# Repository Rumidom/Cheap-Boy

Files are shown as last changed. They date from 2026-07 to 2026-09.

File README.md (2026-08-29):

# Cheap-Boy
<p align="center">
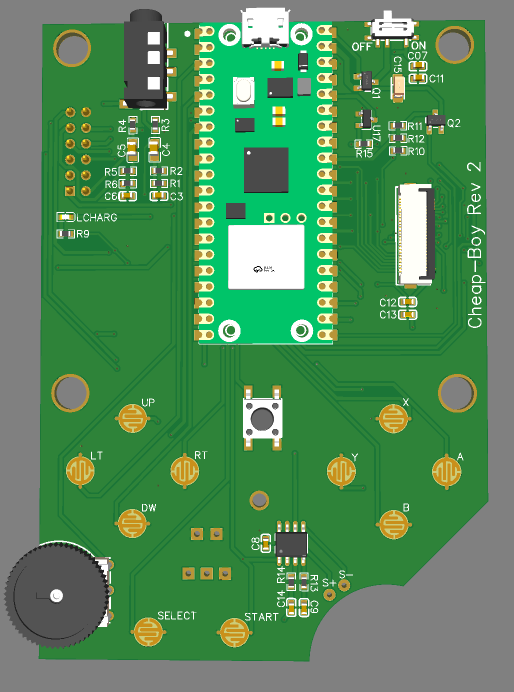
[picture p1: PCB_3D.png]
  
</p>

Cheap-Boy is a motherboard replacement mod for the [SUP 400 in 1](https://bootleggames.fandom.com/wiki/Sup_Game_Box) portable [famiclone](https://en.wikipedia.org/wiki/Famiclone) , the 'SUP 400 in 1' handheld is an interesting piece of Chinese engineering on its own. It has a full NES on a chip, a rechargeable battery, Game-Boy DMG inspired shell, AV output, and can be found on Aliexpress for about U$10 or lower.

I thought it would be interesting to try to replace the main board on this device with one featuring a micro-controller such as the Raspberry Pi Pico, to emulate Game-Boy games. There are already a few emulator projects online leveraging the power of modern micro-controllers for gameboy and retro emulation: [RP2040-GB ](https://github.com/deltabeard/RP2040-GB), [Pico GB](https://github.com/YouMakeTech/Pico-GB), [Walnut-CGB](https://github.com/Mr-PauI/Walnut-CGB
), [retro-go](https://github.com/ducalex/retro-go), [Microbyte](https://hackaday.io/project/176182-microbyte)

Using the components of the sup 400 in 1 should yield an ultra cheap and reasonably powerful handheld. The sup 400 in 1 has already been [reversed enginered](https://hackaday.io/project/175322-dissecting-a-hand-held-noac-console-sup-400-in-1) to support a custom ROM. But as far as I'm aware this is the first attempt at running Game-Boy games on it. 

If you are allergic to cheap white label hardware and would like a more polished and authentic gaming experience, I recommend the [Super DMG](https://github.com/kamicane/Super-DMG-01) which restores new life to actual Nintendo silicon, or the [Gamebub](https://github.com/elipsitz/gamebub) which replicates the Game-Boy hardware on a FPGA aiming at high accuracy, in keeping with the theme, on this project I'll try to reuse as many components from the the SUP 400 in 1 as possible, add a few inexpensive new ones, and try to keep the total cost low. While having a complete feature set.

# Micro-controlers alternatives 

This board is designed for the Raspberry Pi Pico or any of the generic RP2040 variants, but different flavors of micro-controller could be used. There are a few dev board alternatives that share the same form factor and should be compatible. such as the [Wallnut Pico W](https://wiki.walnutpi.com/en/docs/walnutpi_picow/intro/wpi_picow), [ESP32-S3 Pico](https://www.waveshare.com/wiki/ESP32-S3-Pico) or any of the [Raspberry Pico series](https://www.raspberrypi.com/documentation/microcontrollers/pico-series.html#pico2)

## TODO:
- [x] Reverse Engineer 16-bit screen protocol
- [X] Create first revision of the PCB   
- [ ] Write a Screen library for the ILI934X (might need multiple later on, for other types of screen)

## License:
This project is MIT licensed.

## Support


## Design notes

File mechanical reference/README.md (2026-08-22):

# PCB dimensions 

<p align="center">
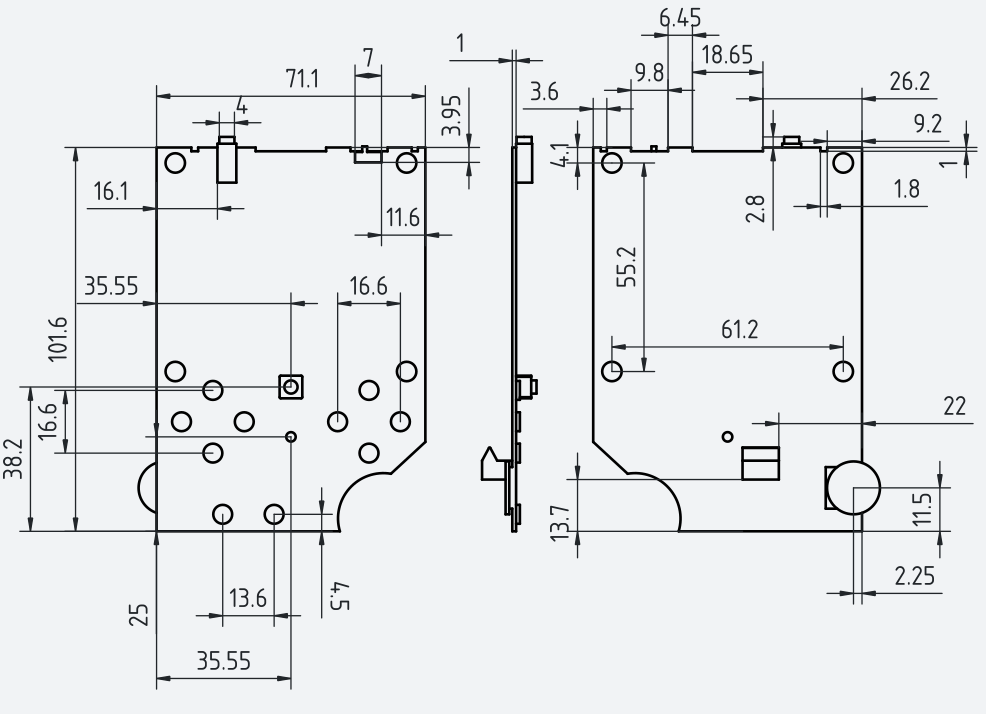
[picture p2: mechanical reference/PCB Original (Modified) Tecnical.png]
  
</p>

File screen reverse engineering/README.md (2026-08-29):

## The Screen
The screen is a 2.4 Inch 240*320 Dots TFT LCD 
<p align="center">
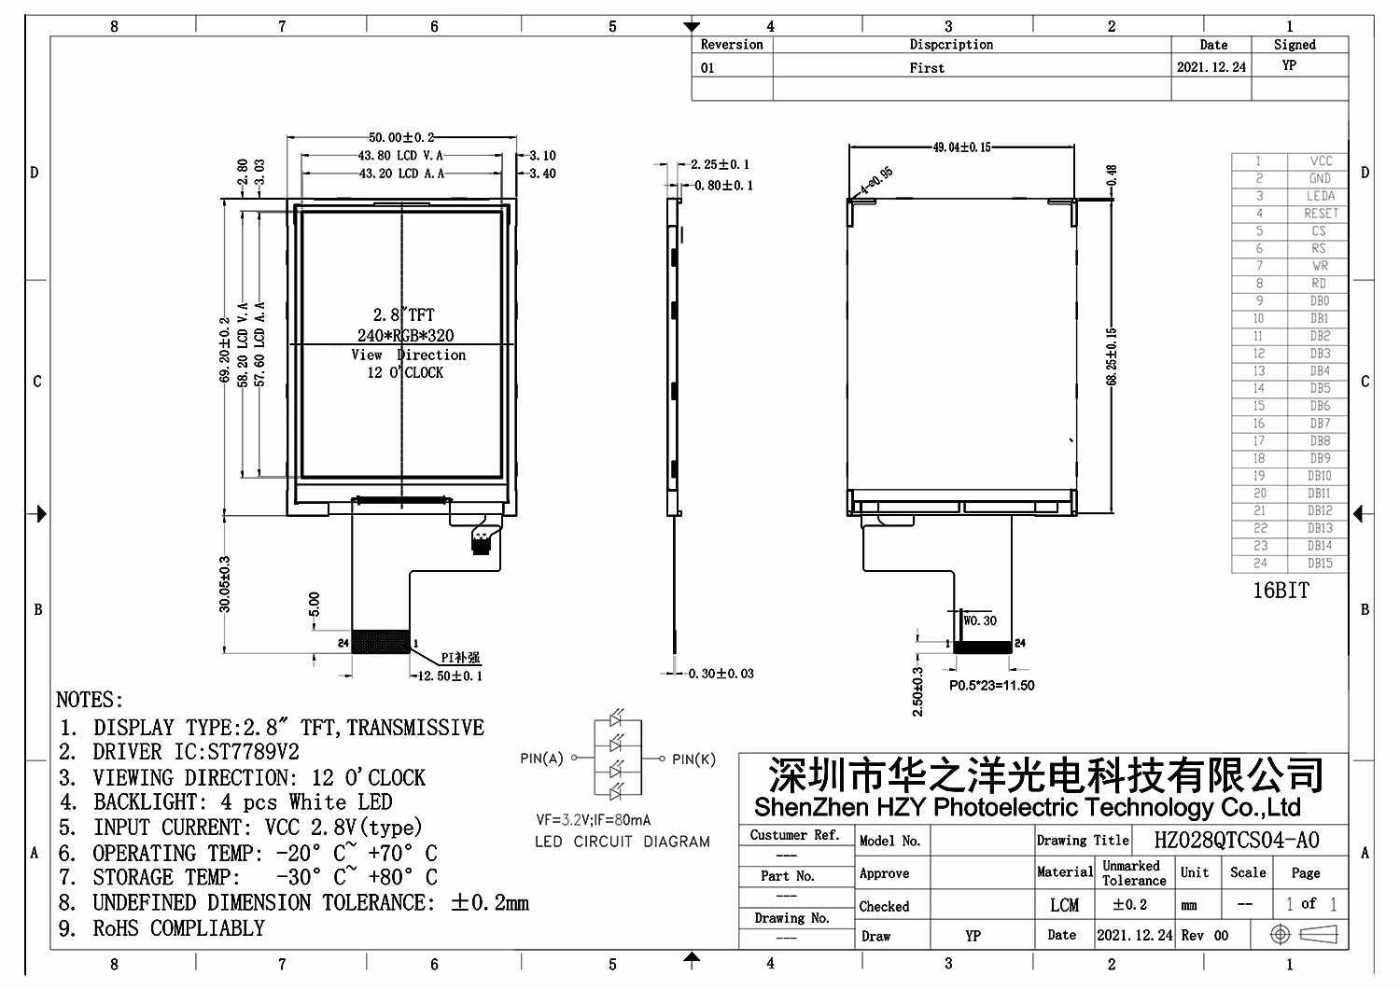
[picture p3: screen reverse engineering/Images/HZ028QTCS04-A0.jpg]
  
</p>

## Reference links
[Alibaba HZ028QTCS04-A0](https://www.alibaba.com/product-detail/China-Manufacturer-s-ST7789V-240-X_1600553862839.html)  
[TWJ28167A0](https://www.alibaba.com/product-detail/2-8-Tft-Lcd-Display-Module_1600589508979.html)  
[TFT024B045](https://www.alibaba.com/product-detail/2-4-240-X-320-TFT_1600669828556.html)  

## Datasheets
[CT024TN01 - Spec Sheet](https://github.com/Rumidom/Cheap-Boy/blob/main/datasheets/CT024TN01_INNOLUX_2.4__A-si_TFT-LCD_Panel_(EN).pdf)  
[ILI9340](https://github.com/Rumidom/Cheap-Boy/blob/main/datasheets/ILI9340.pdf)  
[ILI9341](https://github.com/Rumidom/Cheap-Boy/blob/main/datasheets/ILI9341.pdf)  
[ST7789V](https://github.com/Rumidom/Cheap-Boy/blob/main/datasheets/ST7789V.PDF)  

## Screen Reverse Engineering

### 29/07/2026:
as per the reverse enginering done by [YH-workshop](http://hackaday.io/project/175322-dissecting-a-hand-held-noac-console-sup-400-in-1/log/184885-tft-connections) the screen seems to be based on the ST7789V chipset, and its 2.4 Inch 240*320 Dots, there are a few of these 24 pin screens on alibaba with the same dimensions and flex cable format.

The screen is probably using a 8080 parallel interface, the plan is to use two cascading shift registers to drive DB0 - DB15 and hook the control pins directly to the microcontroller, the NES processor (MOS 6502) has a 8bit data bus and 16bit address bus a portion of these might be exposed in the pins connected to the screen, this could give me more clues to what the processor is doing.

I connected all 24 pins in the connector to a logic analyzer, the numbering in the 24p FPC connector corresponds to the test pads as following:

<p align="center">
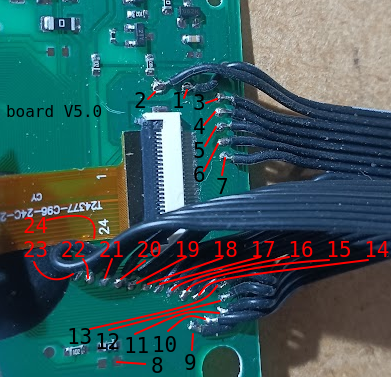
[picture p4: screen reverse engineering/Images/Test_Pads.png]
  
</p>

Capturing the signals on the logic analyzer I got something that resembles the pin-out provided by the first Alibaba screen manufacturer (reference code HZ028QTCS04-A0) the first two pins are indeed VCC(1) and GND(2).While the screen receives data LED(3) and RST(4) are always High, CS(5) is always Low, RS(6) is always High, WR(7) gets short bursts of pulses lasting about 10 microseconds spaced by a pause of about 15 microseconds at High signal. and RD(8) is always High. Apart from the WR pin, the other control pins do not seem to change.

<p align="center">
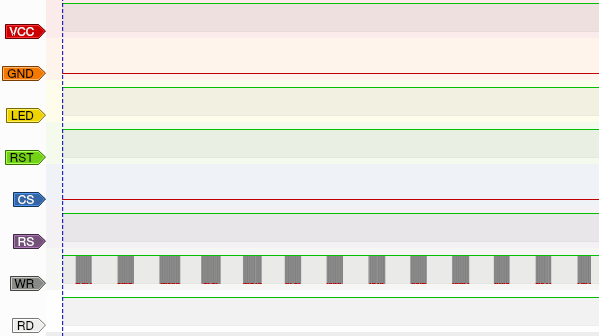
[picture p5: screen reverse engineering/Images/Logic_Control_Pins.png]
  
</p>

The data pins are all active:

<p align="center">
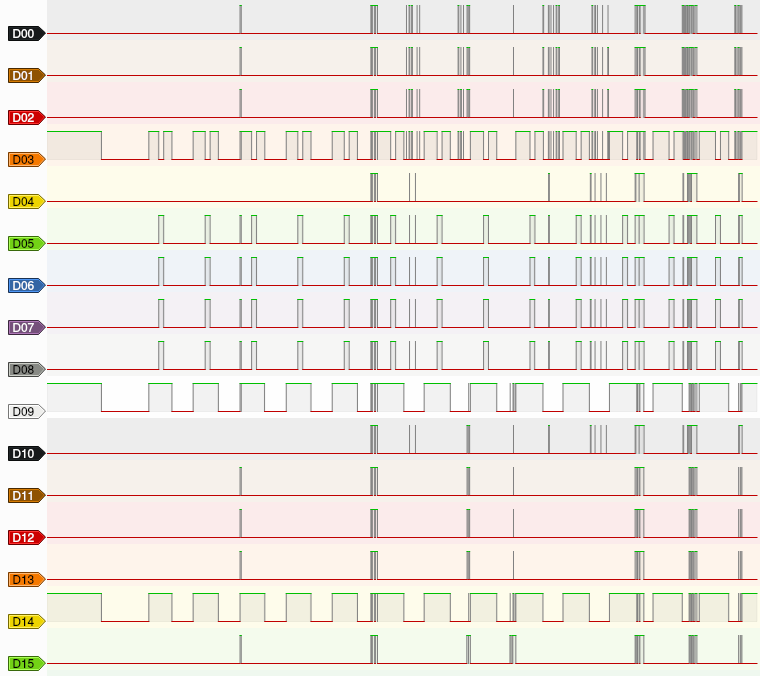
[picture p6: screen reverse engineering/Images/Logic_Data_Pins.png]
  
</p>

The screen is constantly being updated since WR is active even on static screens, which is to be expected since the NES hardware is meant to be used with a CRT TV. 

According to the ST7789V datasheet there are 4 physical pins that determine the screen interface (IM3,IM2,IM1,IM0) ; these are probably inaccessible somewhere inside the screen. But since all 16 data pins are active I'm assuming that the screen is working in "80-16bit parallel I/F" mode:

<p align="center">
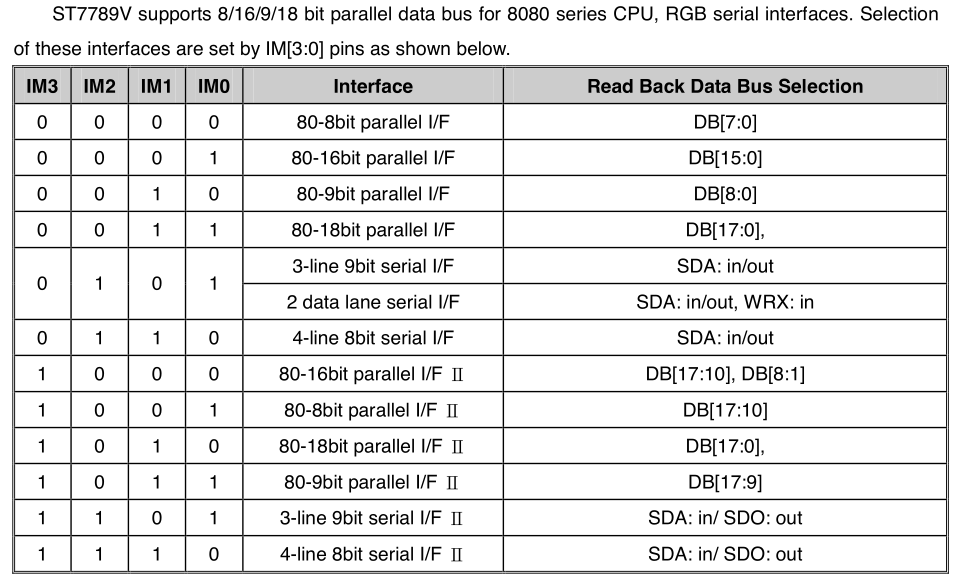
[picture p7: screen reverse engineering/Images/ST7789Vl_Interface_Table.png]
  
</p>

If this is the case I should be able to set the logic analyzer to trigger on the D/CX (manufacturer's RS pin) rising edge and capture the start of a frame:

<p align="center">
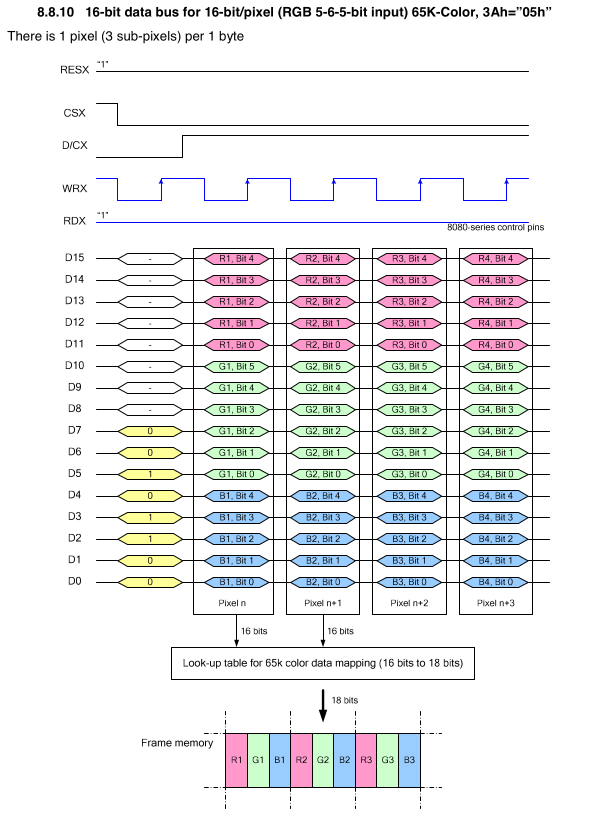
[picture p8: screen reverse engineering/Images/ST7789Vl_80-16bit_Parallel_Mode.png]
  
</p>

however, I haven't been able to do that yet.

### 30/07/2026:

It could be that the pulses I'm seeing on the WR pin are actually a full scanline. The NES operated at 60.0988 Hz according to NTSC standard. This means that each screen frame is drawn in 1/60 seconds, the NES renders 262 scanlines per frame, so each scanline takes (1/60)/262 seconds to draw. equal to 63.6132 microseconds, but that does not match what was measured. 10 microseconds burst + 15 microseconds of pause. At that speed my logic analyzer operating at 120 MHZ might not be fast enough to catch the RS (D/CX) low pulse. 

Under further inspection of the datasheet, I found that the ST7789V also has a VSYNC RGB mode which is more akin to how a CRT monitor works. But that interface requires VSYNC,HSYNC,ENABLE and DOTCLK pins which are not exposed in the connector (assuming that the manufacturer's pinout is correct).

I was also able to capture a long sequence of what seems like bundled data, lasting about 400 microseconds and starting with a long burst on the WR pin followed by a sequence of shorter bursts, but these might just be a result of the NES PPU (Picture Processing Unit) taking pauses to do operations. They do seem to be carrying color information. As you'll see next:

This is the start screen after a reset (where most of the screen is black):  
<p align="center">
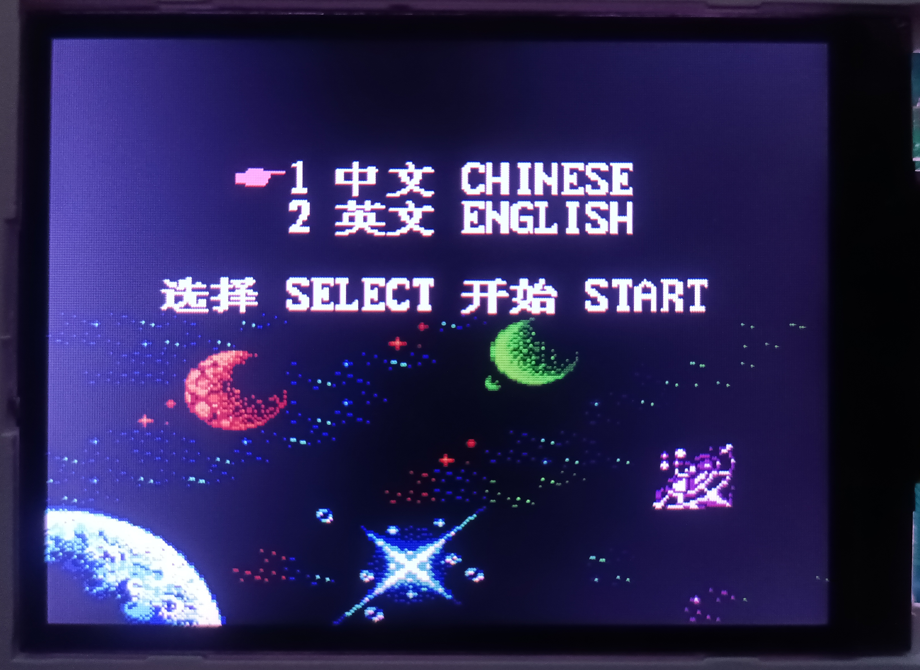
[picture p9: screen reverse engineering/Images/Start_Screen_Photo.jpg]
  
</p>  
<p align="center">
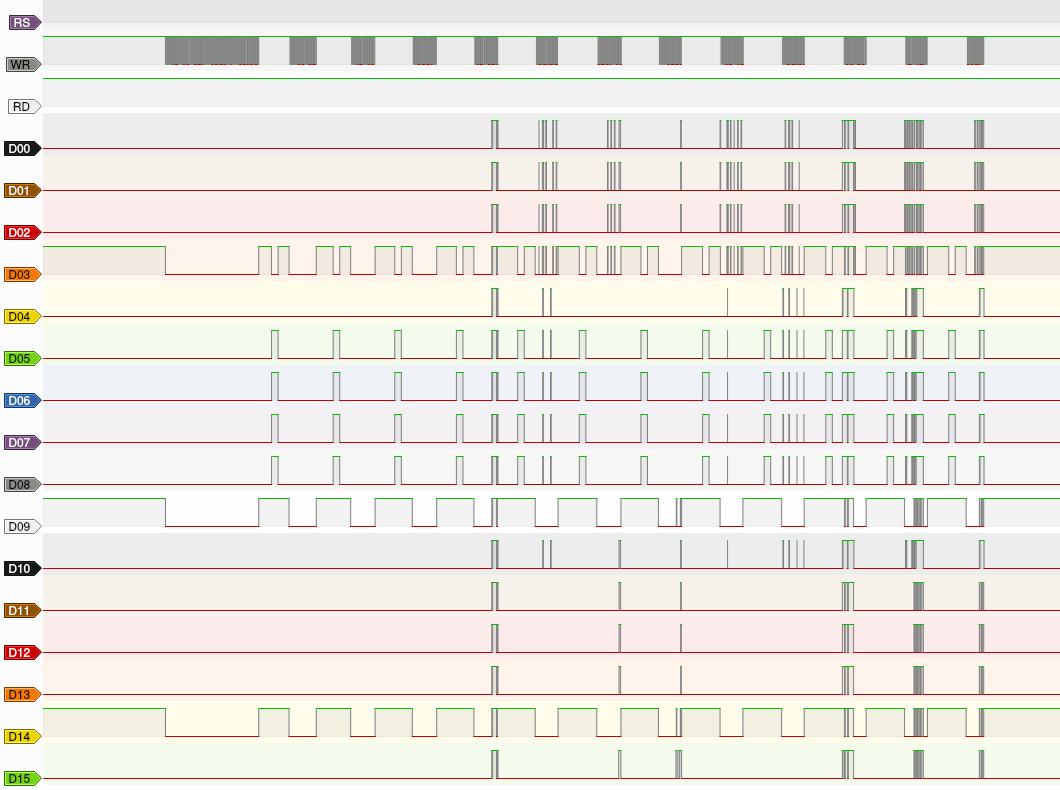
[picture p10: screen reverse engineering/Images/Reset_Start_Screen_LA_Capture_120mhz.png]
  
</p>  
  
And this is the Bubble Bubble 2 game start screen (where most of the screen is white):  
<p align="center">
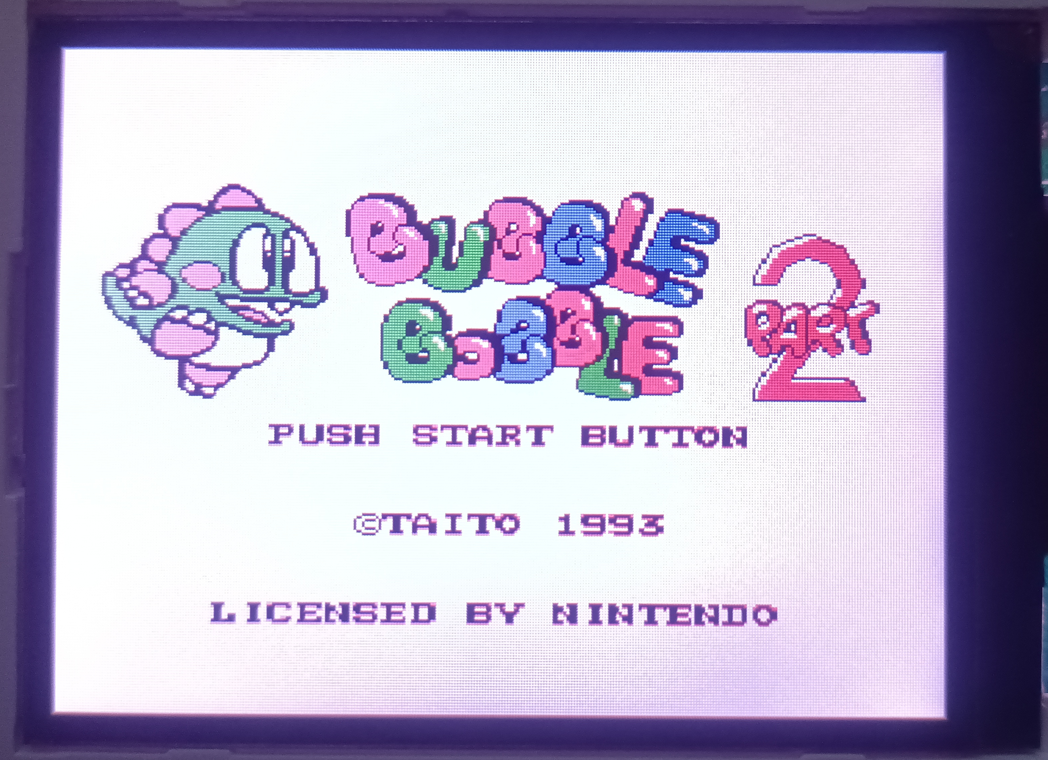
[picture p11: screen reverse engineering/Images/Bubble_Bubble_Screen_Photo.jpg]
  
</p>  
<p align="center">
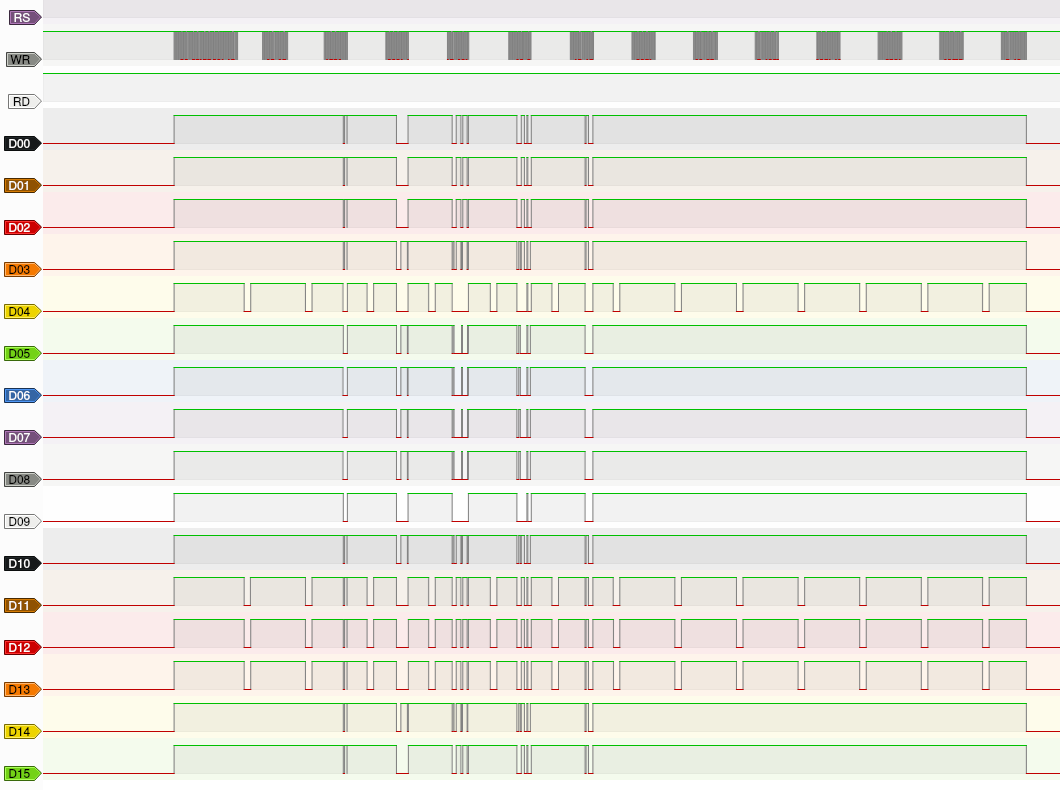
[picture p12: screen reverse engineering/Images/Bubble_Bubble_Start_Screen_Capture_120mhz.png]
  
</p>  

I measured the screen and its actually 2.4 inch, but its indeed 240*320, I'm starting to suspect that this LCD might not be a ST7789V, however the pin-out does seem to match

### 11/08/2026:

I tried using a different [logic analyzer firmware](https://github.com/gusmanb/logicanalyzer) on the pi pico I was using to capture the screen data and got better resolution:

<p align="center">
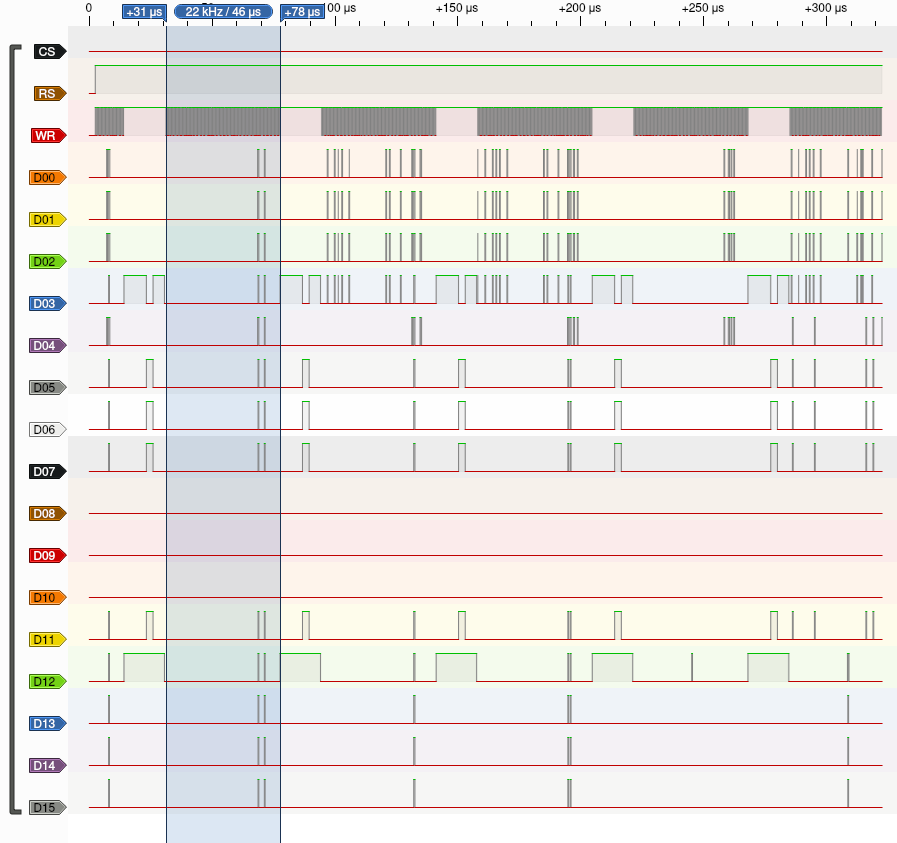
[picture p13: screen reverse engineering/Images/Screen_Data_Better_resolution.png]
  
</p>  

Now I can see that each burst of the WR pin consistently takes 46.44 microseconds plus 17 microseconds of pause, 63.51 microseconds in total, which matches the timing for one scan line of the PPU on the NES. The WR pin has a unusual clock signature composed of short and long pulses:

<p align="center">
  
</p>  

I manually counted the LOW pulses and got a count of 320 pulses which is exactly the number of pixels on each horizontal line on the LCD screen. It should be safe to assume that each burst of clock pulses is a scanline. I have noticed that the games are actually stretched to fit the screen, this is particularly noticeable on the ["Excitebike"](https://gamesdb.launchbox-app.com/games/images/202-excitebike) game, where there is a checkerboard pattern. The screen is probably not driven directly by a NES PPU inside the [COB](https://en.wikipedia.org/wiki/Chip_on_board) on this unit. There should be a translation module or a modified PPU inside, this is most likely a heavily modified version of the Nintendo original. So comparisons should be taken with a grain of salt.

Unfortunately I was only able to capture 4 complete scanlines before the SUP 400 in 1 died, When I disconnected the VCC and GND wires from the Pi Pico they must have shortened out. I decided to remove the back-light on the LCD to see If I can find more clues on the LCD chipset, these are mirrored microscope photos of the back side close to the flex cable:

<p align="center">
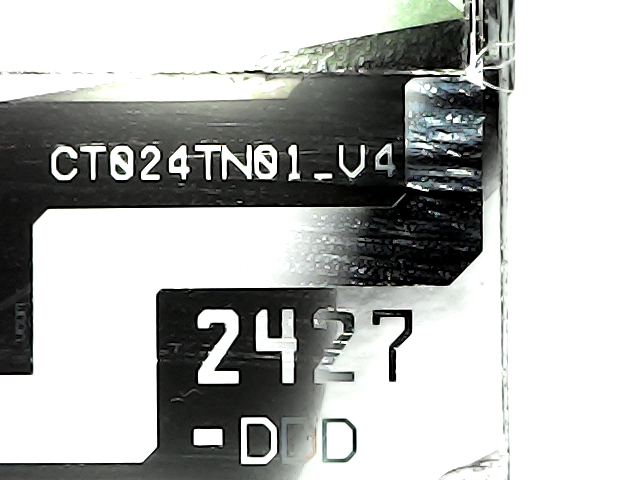
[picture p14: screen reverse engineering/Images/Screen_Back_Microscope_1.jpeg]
  
</p>  

<p align="center">
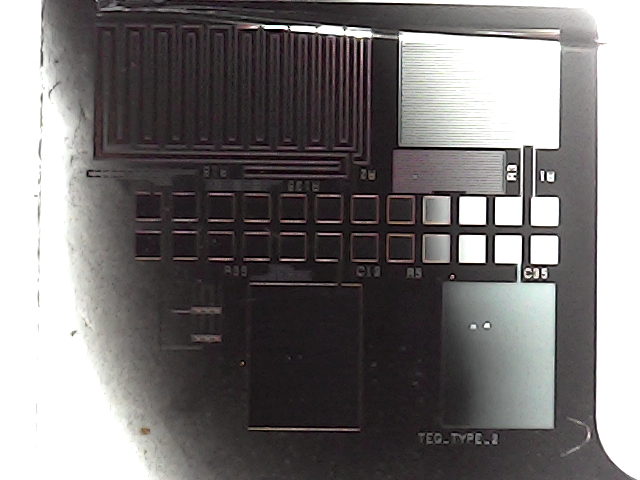
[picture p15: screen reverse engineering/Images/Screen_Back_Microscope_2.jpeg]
  
</p>  

Searching for CT024TN01_V4 online, I found the manufacturer "INNOLUX" which had only a spec-sheet for what seems like a similar screen, next step is to see if I can find what the actual protocol for this screen is, just a hunch, but I think this might be a ILI9340/ILI9341 chipset. Which is just common on these low res screens. I'll try to match the LI9340 datasheet and the new logic analyzer capture data and maybe try decode the capture into a image.

### 12/08/2026:
The ILI9340 datasheet is very similar to the ST7789V datasheet,and it has pretty much the same interfaces, searching for a 16-bit mode I found this table:  

<p align="center">
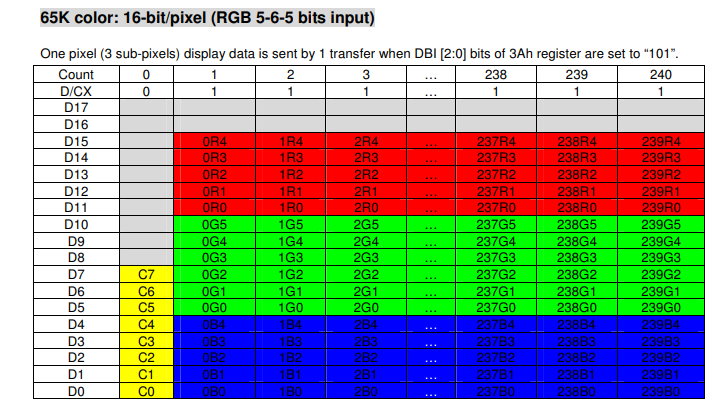
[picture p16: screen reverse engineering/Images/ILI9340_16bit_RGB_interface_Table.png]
  
</p>

DC/RS is pulled low a command is sent and then the colors are sent pixel by pixel until the end of the scanline, natively the screen is in portrait orientation thus the scanline on the table only goes to 240, during screen initialization a command is probably sent to put it in landscape orientation. Still I could not find any start scanline command, or the 
RS pin being pulled low, I made a python script to try to decode the Logic analyzers data, using the same color encoding as the table above, and triggering pixel recording on WR rising edge,I was able to get an image out but the colors seem to be a bit off and it does seem to be losing pixels with the current logic analyzer setup:

<p align="center">
  
</p>

It would be nice if I could get a whole frame to compare, but as I metioned before the screen I was using in now broken, and the new logic analyzer firmware can only capture about 5 scanlines worth of data, at this point I should probably try driving the other screen I have with the interfaces I mentioned previously, I'll try to drive the 16bit bus with shift registers and a pi pico using SPI. each pixel is being drawn at about 11 Mhz maybe half that considering the long pulses the [pi pico](https://raspberrypi.stackexchange.com/questions/132758/what-is-the-pico-max-spi-frequency) maximum clock speed for SPI is 62.5MHz and the [shiftregister](https://e2e.ti.com/support/logic-group/logic/f/logic-forum/819554/sn74hc595-what-is-the-maximum-clock-frequency-when-vcc-3-3v-under-85-degree-ambient-temperature) maximum clock is about 12.5MHz, but this is to shift 1 bit into the 16bit bus, to shift all 16 bits would take 5*16 = 80MHZ, so maintaining 60 hz refresh rate like the NES might not be possible.

<p align="center">
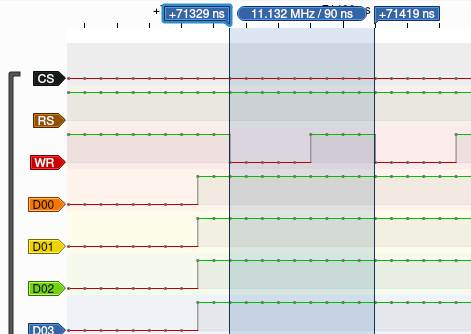
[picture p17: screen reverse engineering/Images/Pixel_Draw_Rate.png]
  
</p>

### 13/08/2026:

Looking at the ILI9340 command list on the datasheet I found this:

<p align="center">
  
</p>

Which should be the command to start writing on the screen, the datasheet also states that there are two transfer modes available, the first one (if I understand correctly) sends a write command and then all the scanlines the second mode sends one command for each scanline (I'm assuming the "Image Data Frame" on the datasheet refers to one scanline). I belive the screen is working in transfer mode 1 since I haven't seen this write command yet, in mode 1 it should only happen once every Screen frame, this is exactly the same for the ST7789V, and the 'Memory Write' command is the same for both 
'XXXXXXXX00101100'.

<p align="center">
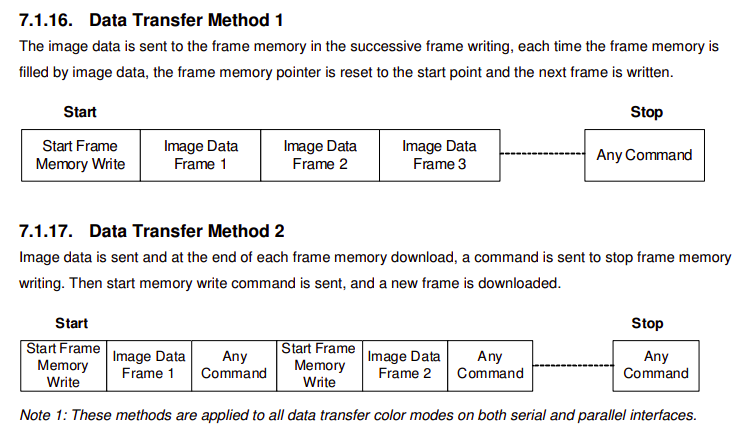
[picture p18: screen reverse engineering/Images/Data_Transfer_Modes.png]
  
</p>

I wrote a small [test script](https://github.com/Rumidom/Cheap-Boy/blob/main/screen%20reverse%20engineering/Screen%20Test%20Micropython/ScreenTest_ili9340.py) in micro-python to send data to the screen using two cascading 74HC595 shift registers and a Pi  Pico, I'm also using another Pi Pico as a logic analyzer to double check the wiring and signals, and was able to send commands to the screen, . on a [micropython library for SPI](https://github.com/jeffmer/micropython-ili9341/tree/master) someone already copied the registers adresses from the datasheet so I'm using those and they seem to work as I was able to get the screen out of sleep and turn off. 

```python
#init Control Pins
BL_pin.value(1)
RST_pin.value(0)
RST_pin.value(1)
CS_pin.value(0)
RS_pin.value(1)
WR_pin.value(1)

#init Shift Registers
SHF_Clck_pin.value(0)
SHF_OUT_EN_pin.value(0)
SHF_Latch_pin.value(0)

# ILI9340/ST7789V
sendScreenCommand(_SLPOUT)
sendScreenCommand(_DISPOFF)
```

<p align="center">
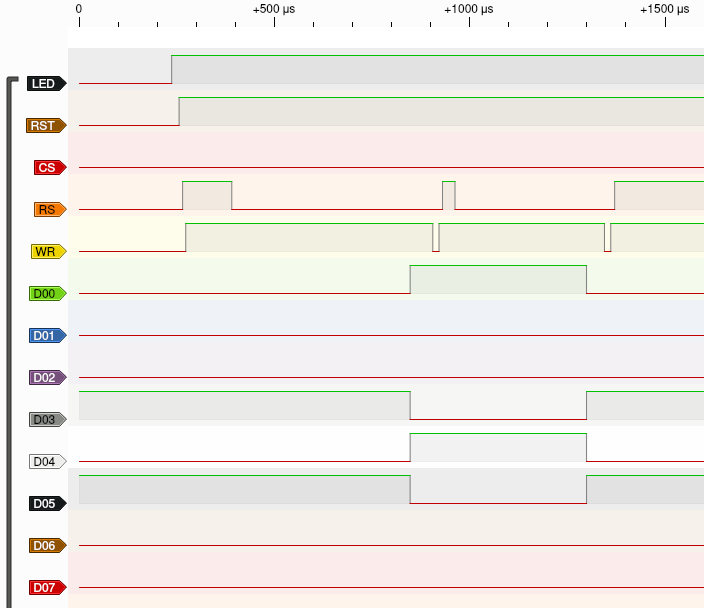
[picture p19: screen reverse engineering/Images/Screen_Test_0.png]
  
</p>

The Micropython library had lots of commands sent on initialization, I don't think they are all necessary or suitable for 16-bit mode, I'll have to test. This is the default state of the configuration registers after reset:

<p align="center">
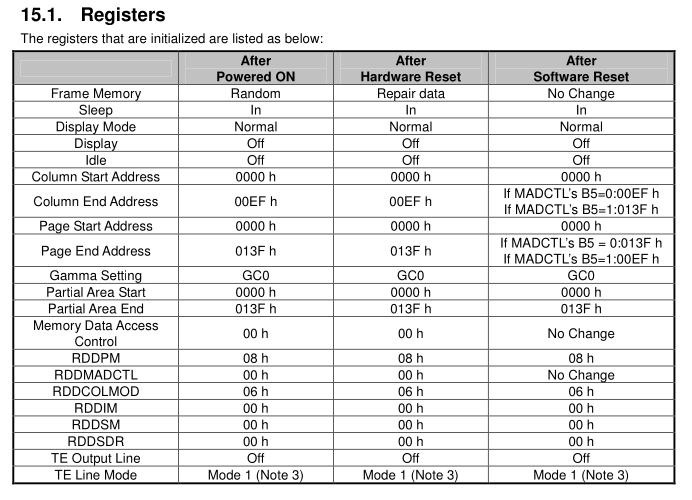
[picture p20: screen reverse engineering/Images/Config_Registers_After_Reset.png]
  
</p>

### 13/08/2027:
Searching for a initialization sequence for the ILI9340, I found this [other library](https://gist.github.com/postmodern/ed6e670999f456ad9f13) I just copied the initialization, and was able to draw 3 color stripes on the screen:

```python
screenInit()

#draw stripes
sendScreenCommand(_RAMWR)
for i in range(240*30):
    sendScreenData_16(0b1111100000000000)
for i in range(240*30):
    sendScreenData_16(0b0000011111100000)
for i in range(240*30):
    sendScreenData_16(0b0000000000011111)
sendScreenCommand(0x00)
```

<p align="center">
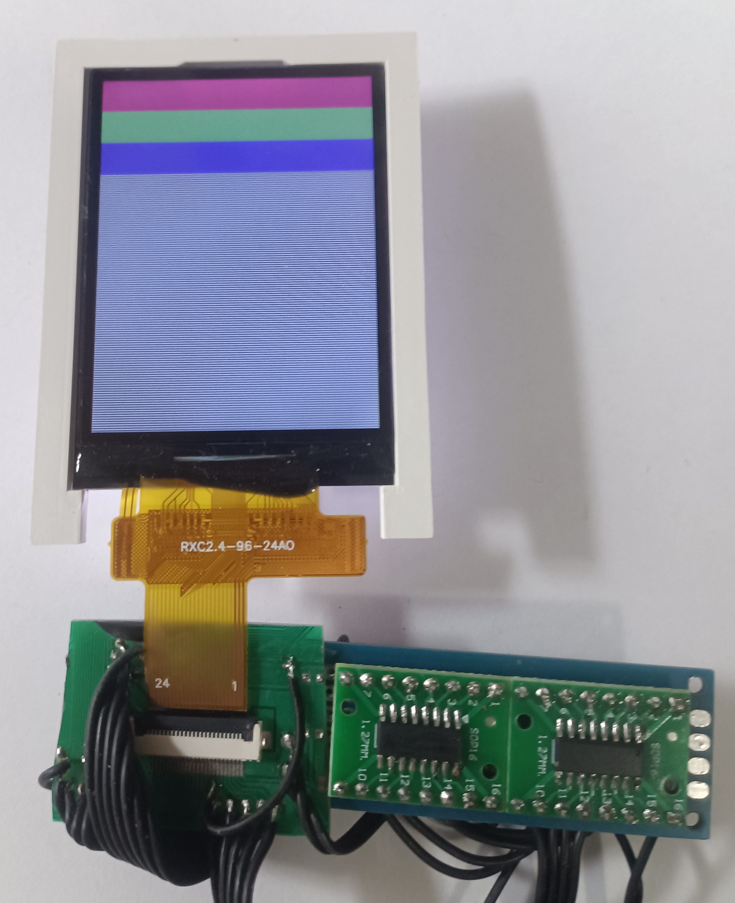
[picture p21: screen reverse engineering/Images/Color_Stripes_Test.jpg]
  
</p>

I think the colors are a bit pastel looking and need correction on initialization to match the panel, but that pretty much confirms it. We are dealing with a ILI934X chipset. It seems like the ST7789 is a sucessor to the Ilitek one, they do have different initialization sequences so I might need to write multiple drivers as I find them, the ILI934X seems to be cheaper and more widely available so should be more comum on 400 in 1 consoles. 

### 29/08/2026:

I bit-banged the first example. But should be able to drive it with PIO closer to the pi pico system frequency. However SPI is Ideal as it would allow for others microcontrollers to be used. Although, I Haven't been able to get that working yet.

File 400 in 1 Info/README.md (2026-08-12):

# Sup 400 in 1 Info

This project focused on making a replacement board for the Sup 400 in 1 but, I think it might be worthwhile doing a little research on the console itself, according to the [bootleggames wiki](https://bootleggames.fandom.com/wiki/Sup_Game_Box) the console has 313 unique games 87 duplicate games, many of which are ports from the [Nintendo NES](https://en.wikipedia.org/wiki/Nintendo_Entertainment_System) these can be found for sale named as "Sup 400 in 1", or just "400 in 1 game console" it runs on a [VTxx](https://bootleggames.fandom.com/wiki/VTxx) chip which is a modified [SOC](https://en.wikipedia.org/wiki/System_on_a_chip) clone of the NES, I was able to sand the [COB](https://en.wikipedia.org/wiki/Chip_on_board) down and take a picture of the silicon die:

<p align="center">
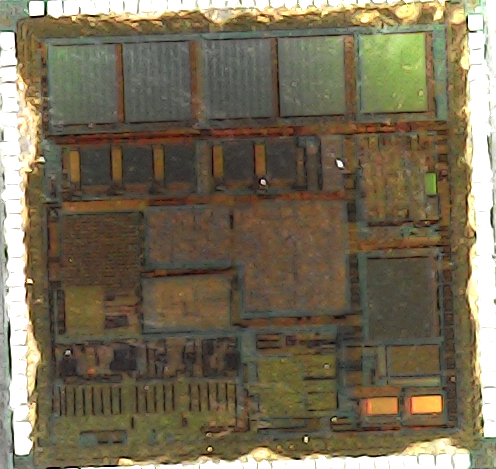
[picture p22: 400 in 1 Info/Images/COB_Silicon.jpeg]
  
</p>
(from the V5 board)  
  
There isn't much technical information online on the inner-workings of this console, but there is a project on [hackaday](https://hackaday.io/project/175322-dissecting-a-hand-held-noac-console-sup-400-in-1) and here on [Github](https://nyh-workshop.github.io/Custom-ROM-Sup-Game-Box-400in1/ROM_dump_analysis) aimed at dumping the systems ROM, both maintained by [YH-workshop](https://github.com/nyh-workshop). According to YH-workshop there are 3 types of screen initialization the last one accepting multiple screen drivers, which is problematic for this project, as I was hoping the console always used the same type of screen. but its likely that they all use the same 16 bit parallel protocol. I bought two of these consoles for reverse engineering they came on similar white label boxes:

<p align="center">
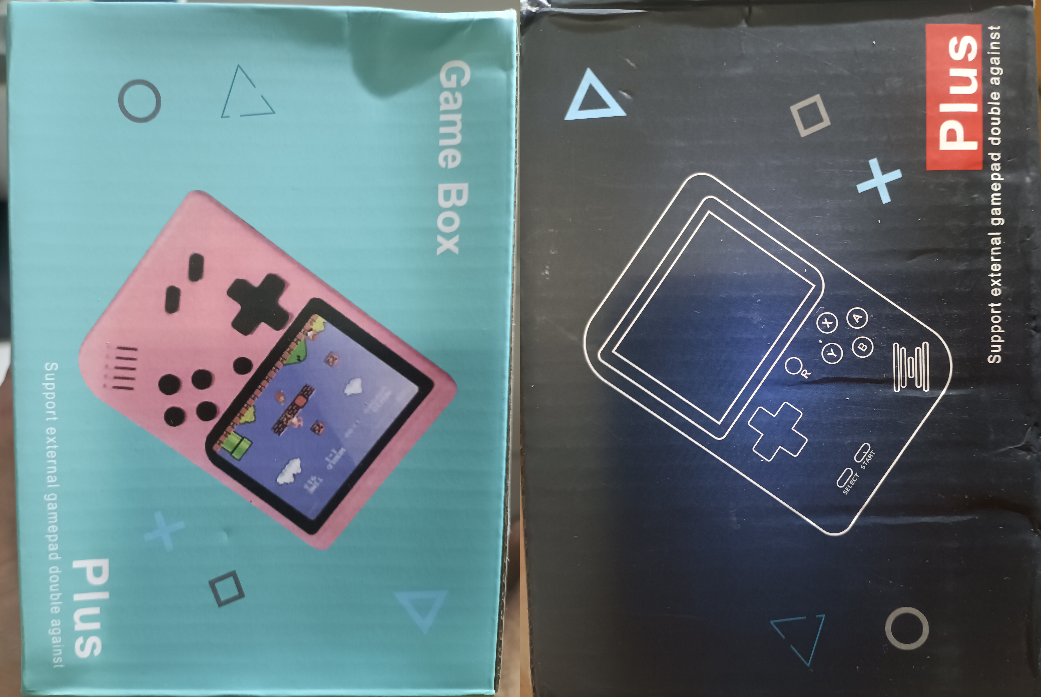
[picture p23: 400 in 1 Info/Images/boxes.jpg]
  
</p>

one had markings indicating that it was a version 5 and the other a version 2:

<p align="center">
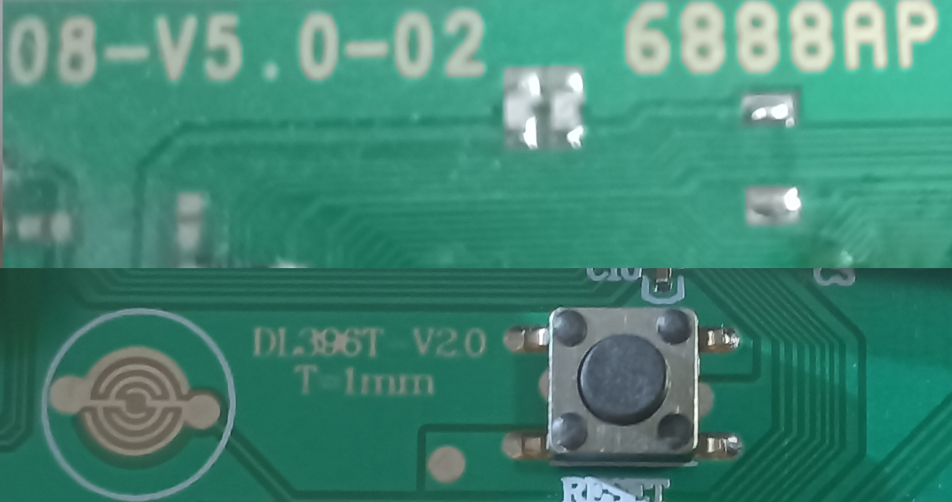
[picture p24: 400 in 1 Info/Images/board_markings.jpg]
  
</p>

both devices have a single layer PCB and used a BL-C5 battery for power, V2 has external audio amplifier, the the v5 had a more streamlined design the audio amplifier was integrated in the COB and the ROM chip was on a what seemed like a SOIC package, Both screens where interchangeable on both the devices.

<p align="center">
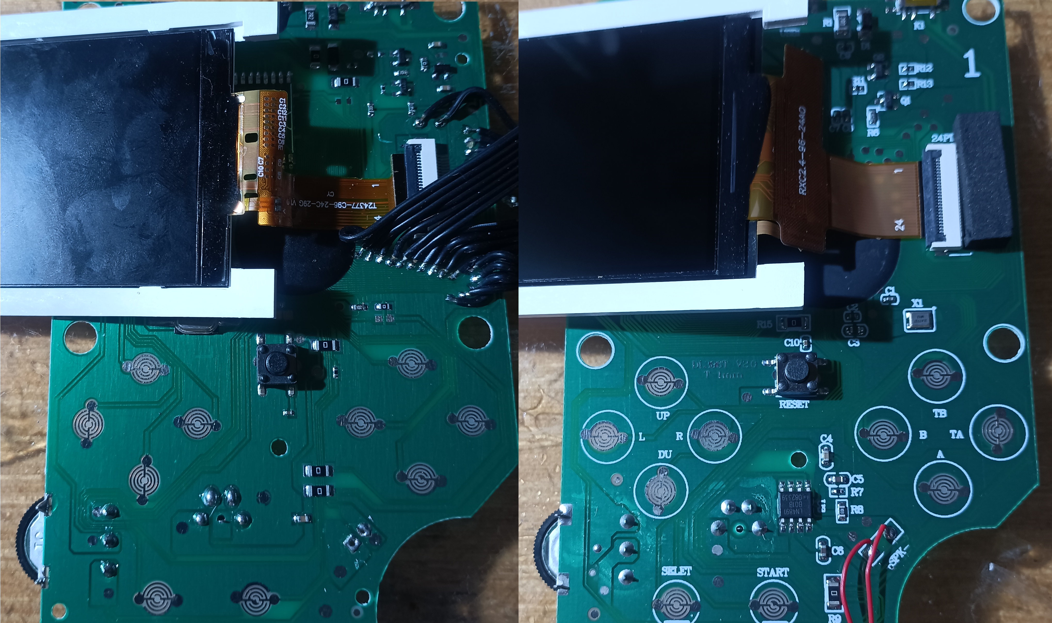
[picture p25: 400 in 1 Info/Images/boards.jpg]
  
</p>

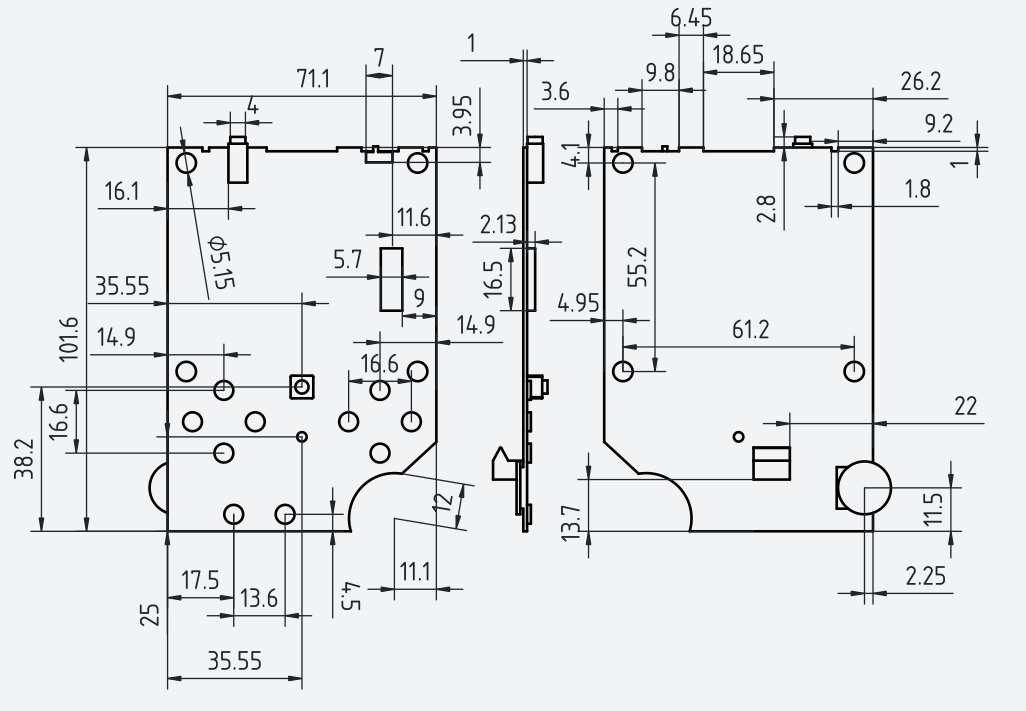
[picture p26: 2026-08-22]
mechanical reference/PCB Original (Modified) Technical.png

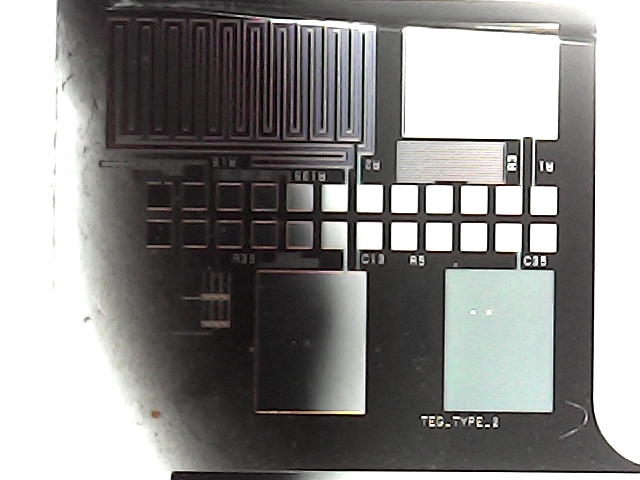
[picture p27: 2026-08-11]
screen reverse engineering/Images/Screen_Back_Microscope_3.jpeg

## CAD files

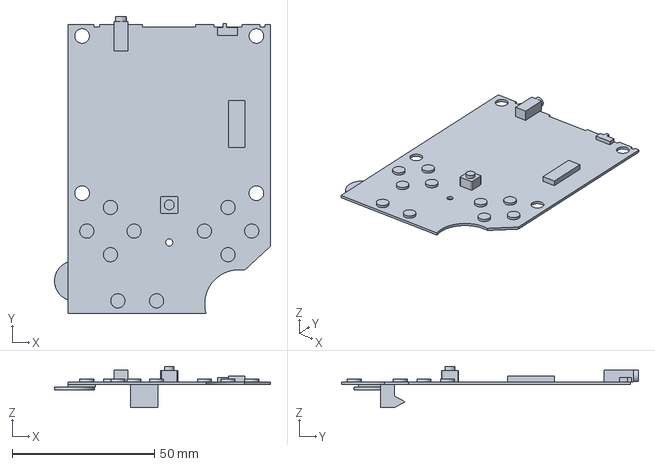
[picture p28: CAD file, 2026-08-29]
mechanical reference/Original_PCB (Modified Outline).FCStd
75.8 x 104.4 x 14.4 mm

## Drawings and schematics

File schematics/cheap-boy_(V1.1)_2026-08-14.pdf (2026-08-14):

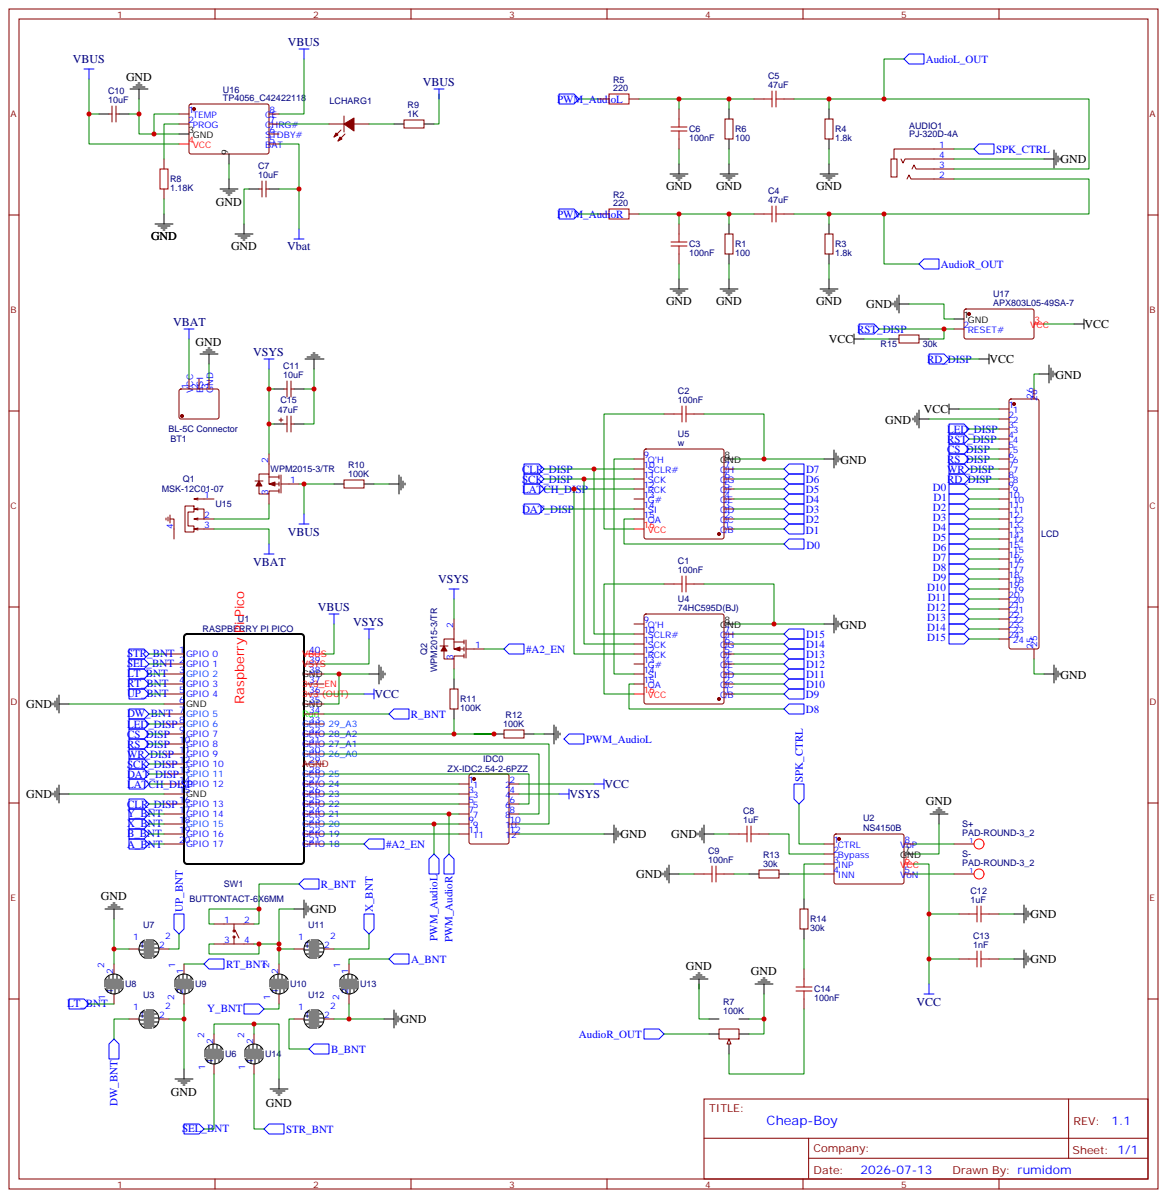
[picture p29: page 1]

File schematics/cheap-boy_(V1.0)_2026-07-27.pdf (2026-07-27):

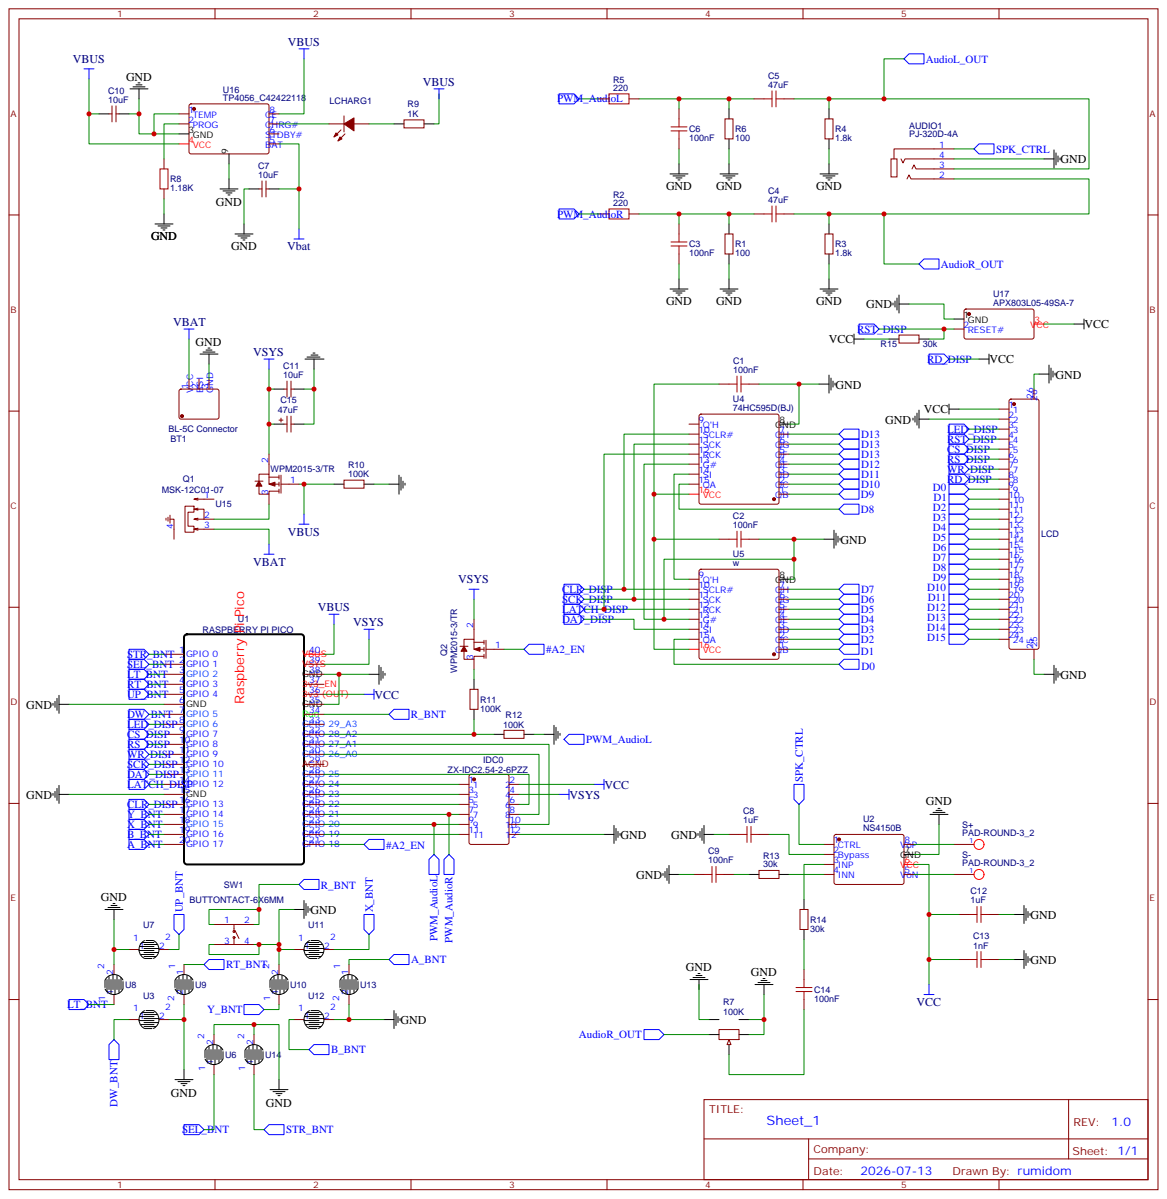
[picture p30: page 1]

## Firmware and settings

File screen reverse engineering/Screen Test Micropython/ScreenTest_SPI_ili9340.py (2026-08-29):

import machine
from machine import Pin,SPI
import time

# ILI9340 Registers
_NOP = const(0x00)       # No Operation
_RDDSDR = const(0x0f)    # Read Display Self-Diagnostic Result
_SLPOUT = const(0x11)    # Sleep Out
_GAMSET = const(0x26)    # Gamma Set
_DISPOFF = const(0x28)   # Display Off
_DISPON = const(0x29)    # Display On
_CASET = const(0x2a)     # Column Address Set
_PASET = const(0x2b)     # Page Address Set
_RAMWR = const(0x2c)     # Memory Write
_RAMRD = const(0x2e)     # Memory Read
_MADCTL = const(0x36)    # Memory Access Control
_VSCRSADD = const(0x37)  # Vertical Scrolling Start Address
_PIXSET = const(0x3a)    # Pixel Format Set
_DTCTRLA = const(0xe8)   # Driver Timing Control A
_DTCTRLB = const(0xea)   # Driver Timing Control B
_PWRONCTRL = const(0xed) # Power on Sequence Control
_PRCTRL = const(0xf7)    # Pump Ratio Control
_PWCTRL1 = const(0xc0)   # Power Control 1
_PWCTRL2 = const(0xc1)   # Power Control 2
_VMCTRL1 = const(0xc5)   # VCOM Control 1
_VMCTRL2 = const(0xc7)   # VCOM Control 2
_FRMCTR1 = const(0xb1)   # Frame Rate Control 1
_DISCTRL = const(0xb6)   # Display Function Control
_ENA3G = const(0xf2)     # Enable 3G
_PGAMCTRL = const(0xe0)  # Positive Gamma Control
_NGAMCTRL = const(0xe1)  # Negative Gamma Control

BL_pin  =  machine.Pin(6,machine.Pin.OUT)
CS_pin  =  machine.Pin(7,machine.Pin.OUT)
RST_pin = machine.Pin(26,machine.Pin.OUT)

RS_pin  =  machine.Pin(20,machine.Pin.OUT)
WR_pin  =  machine.Pin(23,machine.Pin.OUT)
SHF_DataIn_pin  =  machine.Pin(3,machine.Pin.OUT)
SHF_Clck_pin  =  machine.Pin(2,machine.Pin.OUT)

spi = SPI(0,mosi=SHF_DataIn_pin,sck=SHF_Clck_pin,baudrate=400000)  

SHF_OUT_EN_pin  =  machine.Pin(5,machine.Pin.OUT)
SHF_Latch_pin  =  machine.Pin(6,machine.Pin.OUT)
SHF_RST_pin  =  machine.Pin(7,machine.Pin.OUT)

def Clock_WR():
    WR_pin.value(0)
    time.sleep_us(1)
    WR_pin.value(1)

def ResetDataBus():
    SHF_RST_pin.value(0)
    time.sleep_us(1)
    SHF_RST_pin.value(1)

def WriteToDataBus(val,numbits):
    ResetDataBus()
    #hexadecimal 0x0000
    #binary 0b0000000000000000
    SHF_OUT_EN_pin.value(0)
    buf = 0
    for BitIndex in range(numbits-1,-1,-1):
        buf = buf | (1>>BitIndex)
    spi.write(bytearray(buf))
    SHF_Latch_pin.value(1)
    time.sleep_us(1)
    SHF_Latch_pin.value(0)

def sendScreenCommand(command):
    RS_pin.value(0)
    WriteToDataBus(command,8)
    Clock_WR()
    RS_pin.value(1)

def sendScreenData_16(data):
    WriteToDataBus(data,16)
    Clock_WR()

def sendScreenData_8(data):
    WriteToDataBus(data,8)
    Clock_WR()

def setrect(x1,y1,x2,y2):#set coordinates to print on a regeon of the screen
    sendScreenCommand(0x2A);
    sendScreenData_16(x1);
    sendScreenData_16(x2);
    sendScreenCommand(0x2B);
    sendScreenData_16(y1);
    sendScreenData_16(y2);
    sendScreenCommand(0x2C);

#init Control Pins
BL_pin.value(1)
RST_pin.value(0)
RST_pin.value(1)
RS_pin.value(1)
WR_pin.value(1)
CS_pin.value(0)

#init Shift Registers
SHF_Clck_pin.value(0)
SHF_OUT_EN_pin.value(0)
SHF_Latch_pin.value(0)
ResetDataBus()

def screenInit():
    # ILI9340 Initialization
    sendScreenCommand(_SLPOUT)
    sendScreenCommand(_DISPOFF)

    time.sleep_ms(1000)

    #Power control A - Only present on ili9341
    sendScreenCommand(0xcb)
    sendScreenData_8(0x39)
    sendScreenData_8(0x2C)
    sendScreenData_8(0x00)
    sendScreenData_8(0x34)
    sendScreenData_8(0x02)

    #Power control B - Only present on ili9341
    sendScreenCommand(0xCF)
    sendScreenData_8(0x00)
    sendScreenData_8(0xC1)
    sendScreenData_8(0x30)

    #Driver timing control A
    sendScreenCommand(0xE8)
    sendScreenData_8(0x85)
    sendScreenData_8(0x00)
    sendScreenData_8(0x78)

    #Driver timing control B
    sendScreenCommand(0xEA)
    sendScreenData_8(0x00)
    sendScreenData_8(0x00)

    #Power on sequence control
    sendScreenCommand(0xED)
    sendScreenData_8(0x64)
    sendScreenData_8(0x03)
    sendScreenData_8(0x12)
    sendScreenData_8(0x81)

    #Pump ratio control
    sendScreenCommand(0xF7)
    sendScreenData_8(0x20)

    #Power control 1
    sendScreenCommand(0xC0)
    sendScreenData_8(0x23)

    #Power control 2
    sendScreenCommand(0xC1)
    sendScreenData_8(0x10)

    #vcm control
    sendScreenCommand(0xC5)
    sendScreenData_8(0x3E)
    sendScreenData_8(0x28)

    #vcm control 2
    sendScreenCommand(0xC7)
    sendScreenData_8(0x86)

    #memory access control
    sendScreenCommand(0x36)
    sendScreenData_8(0x48)

    #pixel format
    sendScreenCommand(0x3A)
    sendScreenData_8(0x55)

    #frameration control,normal mode full colours
    sendScreenCommand(0xB1)
    sendScreenData_8(0x00)
    sendScreenData_8(0x18)

    #display function control
    sendScreenCommand(0xB6)
    sendScreenData_8(0x08)
    sendScreenData_8(0x82)
    sendScreenData_8(0x27)

    #gamma function disable
    sendScreenCommand(0xF2)
    sendScreenData_8(0x00)

    #gamma curve selected
    sendScreenCommand(0x26)
    sendScreenData_8(0x01)

    #set positive gamma correction
    sendScreenCommand(0xE0)
    sendScreenData_8(0x0F)
    sendScreenData_8(0x31)
    sendScreenData_8(0x2B)
    sendScreenData_8(0x0C)
    sendScreenData_8(0x0E)
    sendScreenData_8(0x08)
    sendScreenData_8(0x4E)
    sendScreenData_8(0xF1)
    sendScreenData_8(0x37)
    sendScreenData_8(0x07)
    sendScreenData_8(0x10)
    sendScreenData_8(0x03)
    sendScreenData_8(0x0E)
    sendScreenData_8(0x09)
    sendScreenData_8(0x00)

    #set negative gamma correction
    sendScreenCommand(0xE1)
    sendScreenData_8(0x00)
    sendScreenData_8(0x0E)
    sendScreenData_8(0x14)
    sendScreenData_8(0x03)
    sendScreenData_8(0x11)
    sendScreenData_8(0x07)
    sendScreenData_8(0x31)
    sendScreenData_8(0xC1)
    sendScreenData_8(0x48)
    sendScreenData_8(0x08)
    sendScreenData_8(0x0F)
    sendScreenData_8(0x0C)
    sendScreenData_8(0x31)
    sendScreenData_8(0x36)
    sendScreenData_8(0x0F)

    #exit sleep
    sendScreenCommand(0x11)
    time.sleep_ms(120)

    #display on
    sendScreenCommand(0x29)

screenInit()

#draw stripes
sendScreenCommand(_RAMWR)
for i in range(240*30):
    sendScreenData_16(0b1111100000000000)
for i in range(240*30):
    sendScreenData_16(0b0000011111100000)
for i in range(240*30):
    sendScreenData_16(0b0000000000011111)
sendScreenCommand(0x00)























































































































































































































 

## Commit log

2026-07-27 adding research material, and first schematic draft
    [Original_PCB-Body.step, Original_PCB.FCStd]
2026-07-29 adding screen reverse engineering
    [Original_PCB (Modified).FCStd, Original_PCB (Modified).step]
2026-08-12 adding capture decoding
    [Reset_Start_Screen_Idle_100Mhz_Better_Resolution(gusmanb pi pico firmware).csv]
2026-08-14 testing the screen with a pi pico
    [test.csv]
2026-08-14 updating schematics
2026-08-15 adding buttons positions on mechanical reference
    [Original_PCB (Modified).FCStd]
2026-08-15 adding technical drawings
    [Original_PCB (Modified).FCStd]
2026-08-15 Update README to reflect PCB dimensions
2026-08-22 adding to reverse engineering
    [Original_PCB (Modified).FCStd]
2026-08-22 updating technical drawing with display conector
    [Original_PCB (Modified).FCStd]
2026-08-29 adding PCB img
    [Original_PCB (Modified).FCStd]
2026-08-29 Adding PCB Img to README
2026-09-28 updating membraine buttons
    [Original_PCB (Modified Outline).FCStd, Original_PCB (Modified)-Body.step, Original_PCB (Modified).step]
2026-09-30 adding screw hole
